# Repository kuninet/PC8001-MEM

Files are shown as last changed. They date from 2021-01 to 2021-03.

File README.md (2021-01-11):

# PC-8001 32k x4バンク拡張メモリーボード

## 概要
- PC-8001のN-BASIC ROM/空きROM領域(アドレス0000h～7FFFh)の裏側に4バンクのメモリーを増設するボードです。
- バンク切り替えはPC-8012/8801などと同様の操作にしています。

## 拡張メモリー切り替え
- I/Oアドレス E2 : 
  - bit0 (01h)
    - 0 : N-BASIC ROM READ
    - 1 : 拡張RAM READ
  - bit4 (10h)
    - 1 : 拡張RAM WRITE
- I/Oアドレス E3 : 
  - メモリーバンク番号を0～4で指定します。リセット時デフォルトは0です。 
  - 128kB SRAMを4分割(4バンク)切り替えを実施して使用できます。
  - 0000h～7FFFhまでが切り替わるため、N-BASIC ROMは見えなくなります。(バンク切り替えし、書き込みのみ許可しておいて 切り替えることは可能)

## ライセンス
- 本リポジトリのファイルはMITライセンスで公開します。

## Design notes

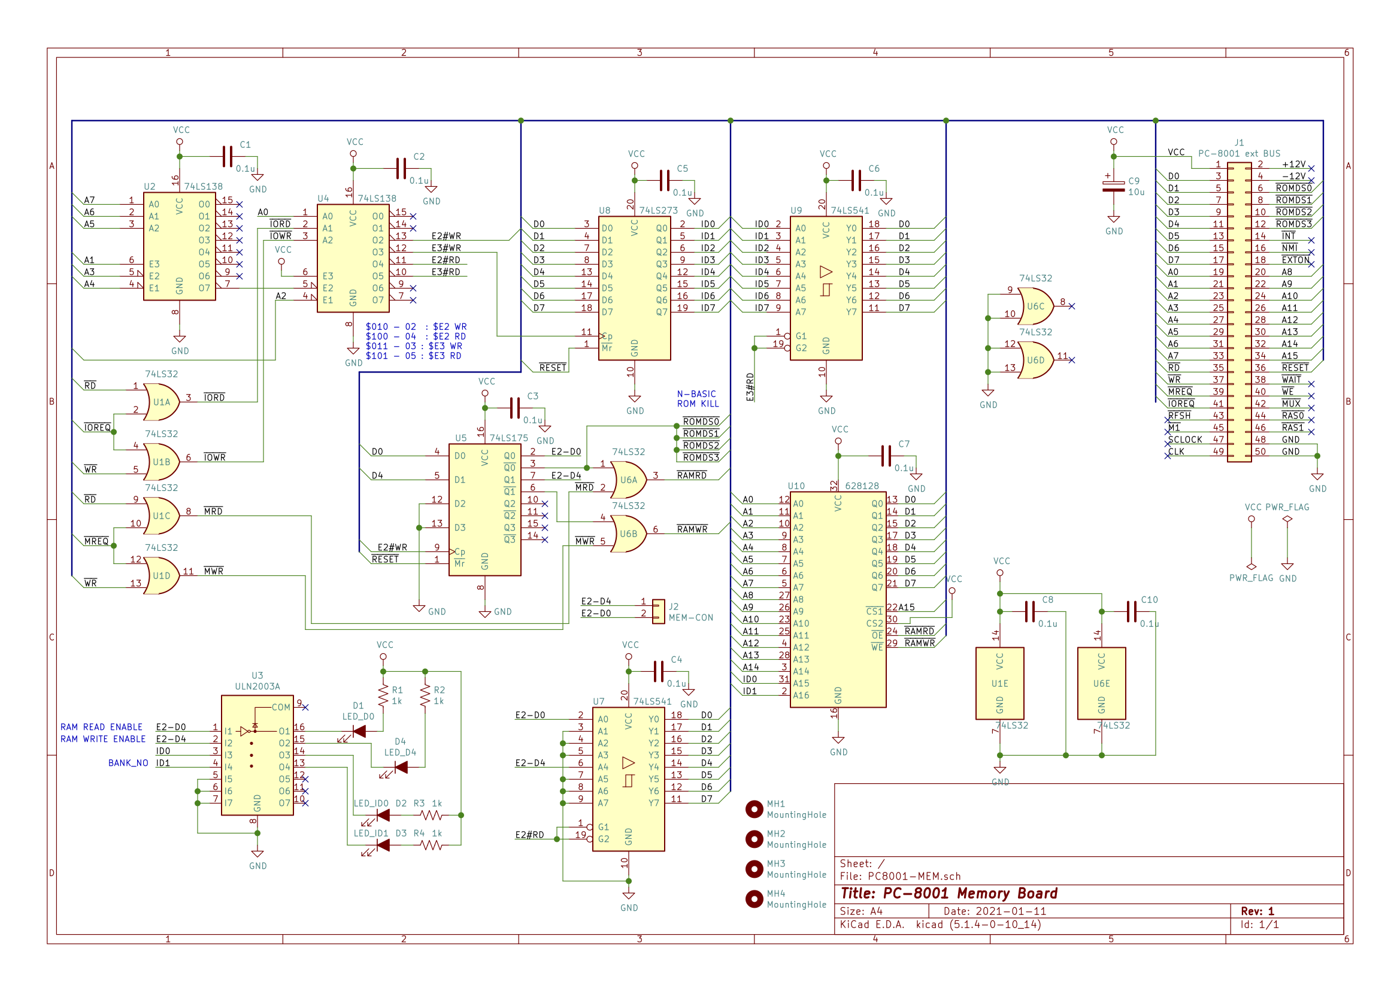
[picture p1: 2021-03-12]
img/PC8001-MEM.png

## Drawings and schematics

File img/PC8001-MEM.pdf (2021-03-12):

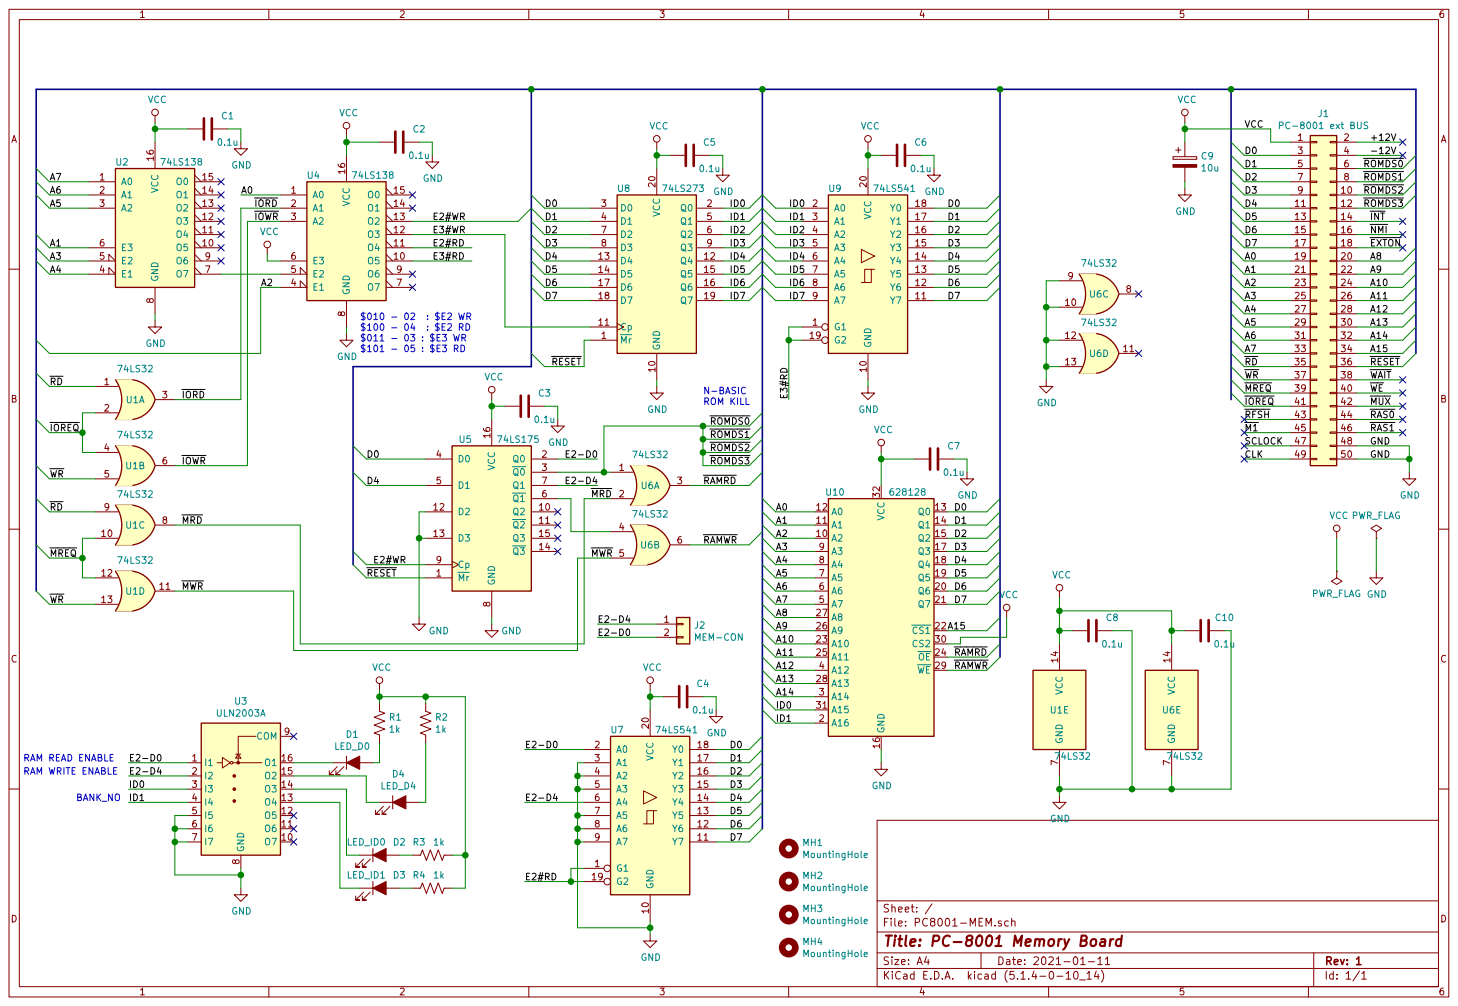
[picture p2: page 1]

8 COM 9 U3 ULN2003A GND GND GND

File: PC8001-MEM.sch Sheet: /
Id: 1/1 Title: PC-8001 Memory Board

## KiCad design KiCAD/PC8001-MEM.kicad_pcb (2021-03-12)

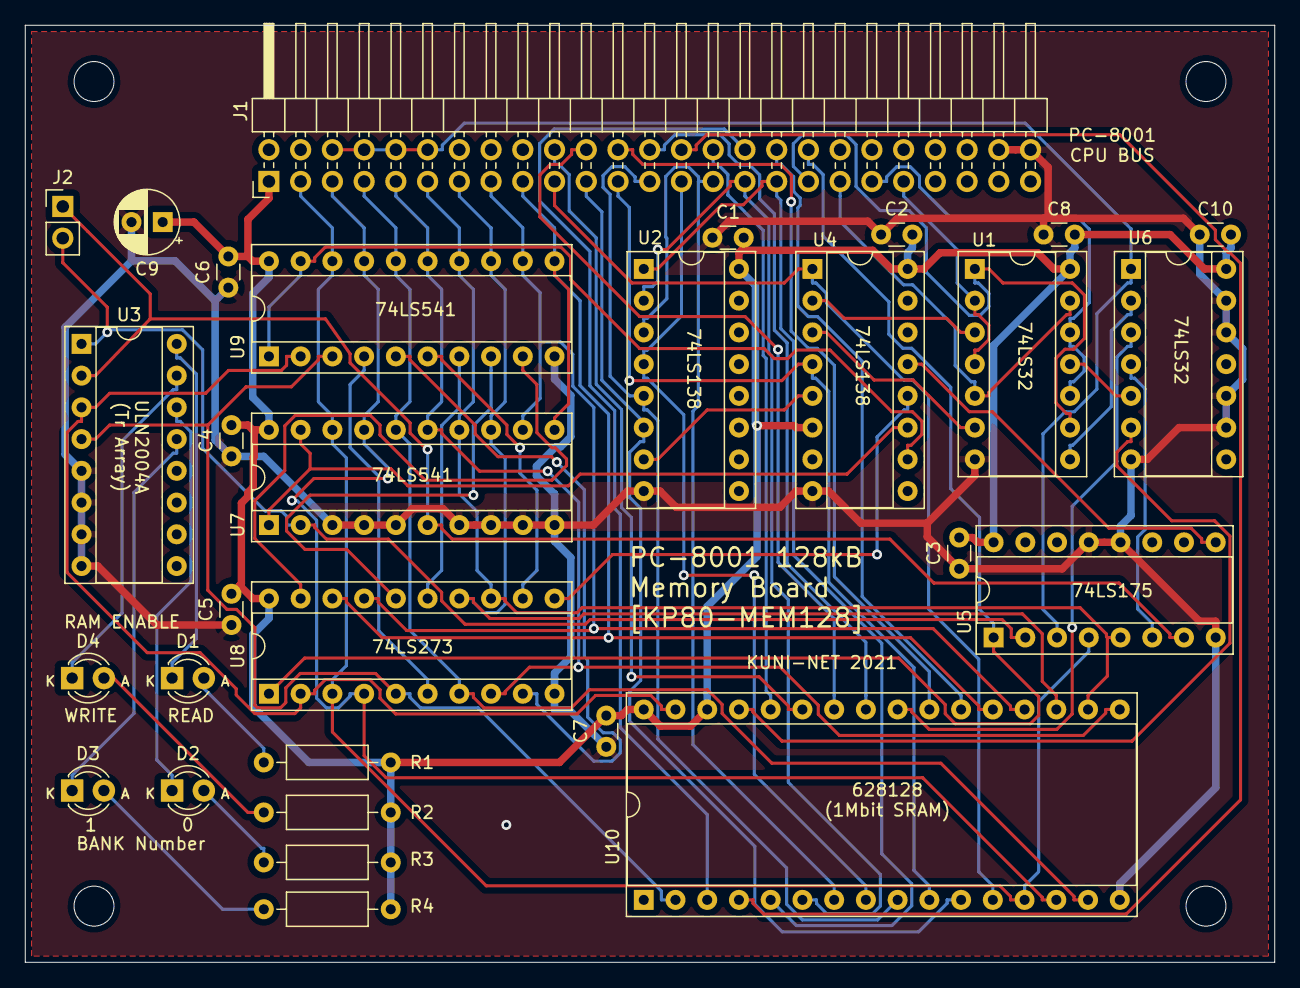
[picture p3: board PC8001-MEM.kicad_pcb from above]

Board: 2 copper layers, 100.0 x 75.0 mm, 34 parts (0 on the bottom side), 62 nets.

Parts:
C1, C2, C3, C4, C5, C6, C7, C8, C10: 0.1u; C_Disc_D3.0mm_W1.6mm_P2.50mm
C9: 10u; CP_Radial_D5.0mm_P2.50mm
D1: LED_D0; LED_D3.0mm
D2: LED_ID0; LED_D3.0mm
D3: LED_ID1; LED_D3.0mm
D4: LED_D4; LED_D3.0mm
J1: PC-8001 ext BUS; PinHeader_2x25_P2.54mm_Horizontal
J2: MEM-CON; PinHeader_1x02_P2.54mm_Vertical
MH1, MH2, MH3, MH4: MountingHole; MountingHole_3.2mm_M3
R1, R2, R3, R4: 1k; R_Axial_DIN0207_L6.3mm_D2.5mm_P10.16mm_Horizontal
U1, U6: 74LS32; DIP-14_W7.62mm_Socket
U2, U4: 74LS138; DIP-16_W7.62mm_Socket
U3: ULN2003A; DIP-16_W7.62mm_Socket
U5: 74LS175; DIP-16_W7.62mm_Socket
U7, U9: 74LS541; DIP-20_W7.62mm_Socket
U8: 74LS273; DIP-20_W7.62mm_Socket
U10: 628128; DIP-32_W15.24mm_Socket

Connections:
/A0: J1.19, U4.1, U10.12
/A1: J1.21, U2.6, U10.11
/A2: J1.23, U4.4, U10.10
/A3: J1.25, U2.5, U10.9
/A4: J1.27, U2.4, U10.8
/A5: J1.29, U2.3, U10.7
/A6: J1.31, U2.2, U10.6
/A7: J1.33, U2.1, U10.5
/A8: J1.20, U10.27
/A9: J1.22, U10.26
/A10: J1.24, U10.23
/A11: J1.26, U10.25
/A12: J1.28, U10.4
/A13: J1.30, U10.28
/A14: J1.32, U10.3
/A15: J1.34, U10.22
/D0: J1.3, U5.4, U7.18, U8.3, U9.18, U10.13
/D1: J1.5, U7.17, U8.4, U9.17, U10.14
/D2: J1.7, U7.16, U8.7, U9.16, U10.15
/D3: J1.9, U7.15, U8.8, U9.15, U10.17
/D4: J1.11, U5.5, U7.14, U8.13, U9.14, U10.18
/D5: J1.13, U7.13, U8.14, U9.13, U10.19
/D6: J1.15, U7.12, U8.17, U9.12, U10.20
/D7: J1.17, U7.11, U8.18, U9.11, U10.21
/E2#RD: U4.11, U7.1, U7.19
/E2#WR: U4.13, U5.9
/E2-D0: J2.2, U3.1, U5.2, U7.2
/E2-D4: J2.1, U3.2, U5.7, U7.6
/E3#RD: U4.10, U9.1, U9.19
/E3#WR: U4.12, U8.11
/ID0: U3.3, U8.2, U9.2, U10.31
/ID1: U3.4, U8.5, U9.3, U10.2
/ID2: U8.6, U9.4
/ID3: U8.9, U9.5
/ID4: U8.12, U9.6
/ID5: U8.15, U9.7
/ID6: U8.16, U9.8
/ID7: U8.19, U9.9
/~IORD: U1.3, U4.2
/~IOREQ: J1.41, U1.2, U1.4
/~IOWR: U1.6, U4.3
/~MRD: U1.8, U6.2
/~MREQ: J1.39, U1.10, U1.12
/~MWR: U1.11, U6.5
/~RAMRD: U6.3, U10.24
/~RAMWR: U6.6, U10.29
/~RD: J1.35, U1.1, U1.9
/~RESET: J1.36, U5.1, U8.1
/~ROMDS0: J1.6, J1.8, J1.10, J1.12, U5.3, U6.1
/~WR: J1.37, U1.5, U1.13
GND: C1.1, C2.1, C3.1, C4.1, C5.1, C6.1, C7.1, C8.1, C9.2, C10.1, J1.48, J1.50, U1.7, U2.8, U3.5, U3.6, U3.7, U3.8, U4.8, U5.8, U5.12, U5.13, U6.7, U6.9, U6.10, U6.12, U6.13, U7.3, U7.4, U7.5, U7.7, U7.8, U7.9, U7.10, U8.10, U9.10, U10.16
unnamed: D1.1, U3.16
unnamed: D1.2, R1.2
unnamed: D2.1, U3.14
unnamed: D2.2, R3.2
unnamed: D3.1, U3.13
unnamed: D3.2, R4.2
unnamed: D4.1, U3.15
unnamed: D4.2, R2.2
unnamed: U2.7, U4.5
unnamed: U5.6, U6.4
VCC: C1.2, C2.2, C3.2, C4.2, C5.2, C6.2, C7.2, C8.2, C9.1, C10.2, J1.1, R1.1, R2.1, R3.1, R4.1, U1.14, U2.16, U4.6, U4.16, U5.16, U6.14, U7.20, U8.20, U9.20, U10.30, U10.32

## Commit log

2021-01-11 README追加
    [PC8001-MEM.sch]
2021-01-11 README.md 名前間違い訂正
2021-01-11 回路図修正、イメージ追加
    [PC8001-MEM.sch]
2021-01-11 アドレス E2用 LED追加
    [PC8001-MEM.sch]
2021-01-11 回路修正(ROM KILL間違い)
    [PC8001-MEM.sch]
2021-01-13 E2hのレジスタを74LS175へ変更、LEDドライバ変更
    [PC8001-MEM.sch]
2021-01-13 回路図イメージ差し替え
2021-01-17 N-BASIC COPYデモ
2021-01-17 LS273、LS175のCp信号の部分の間違い訂正
    [PC8001-MEM.sch]
2021-01-17 回路図差し替え
2021-01-21 Revert "回路図差し替え"
    This reverts commit 483a819fbeebb61eaf4f5652be9b0b19720a5eab.
2021-01-21 Revert "LS273、LS175のCp信号の部分の間違い訂正"
    This reverts commit dc92f6c23538d2a9134d8bc83470156b4a3e76cd.
    [PC8001-MEM.sch]
2021-02-07 プリント基板化検討
    [PC8001-MEM.dsn, PC8001-MEM.sch]
2021-02-07 パターン更新
    [PC8001-MEM.kicad_pcb]
2021-02-18 ガーバーデータ出力
    [PC8001-MEM.GBL, PC8001-MEM.GBO, PC8001-MEM.GBP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]
2021-03-12 8k SRAMボードコントロール信号端子追加・ガーバーデータ再出力
    [PC8001-MEM.GBL, PC8001-MEM.GBO, PC8001-MEM.GBP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]
2021-03-12 回路図変更
    [PC8001-MEM.sch]
